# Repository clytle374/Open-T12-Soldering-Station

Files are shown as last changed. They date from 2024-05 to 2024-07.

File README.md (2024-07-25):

# Open-T12-Soldering-Station-
This is a clone of the cheap T12 soldering stations, attempting to eliminate the shortfalls of cheap.  Useless without the fine firmware from https://github.com/deividAlfa/stm32_soldering_iron_controller

It has provisions for a backup battery. Jumper selectable between internal and external NTC as some of the new handles don't contain a NTC, so this gives you the option if you don't want to add one to your handle.  There are also jumper option for configuring different soldering handles.  It is setup to use the 1.3” 6 pin OLED display.  

The pinouts match the KSGER stations for compatibility with the above mentioned handles. There is no provision for the real time clock in the firmware, I see it as useless.

Some of the cheap boards had issue with the linear voltage regulator dropping out from thermal protection as the power was quite high dropping from 24V to 3.3V.  This design uses a switching regulator to step down from 24V ot 5V, and then a 3.3V linear regulator for a clean 3.3V supply.

Much more information on the many models out there at the above mentioned site for the firmware. I created this as it is impossible to tell exactly what you are buying from the suppliers.

Front

PCB

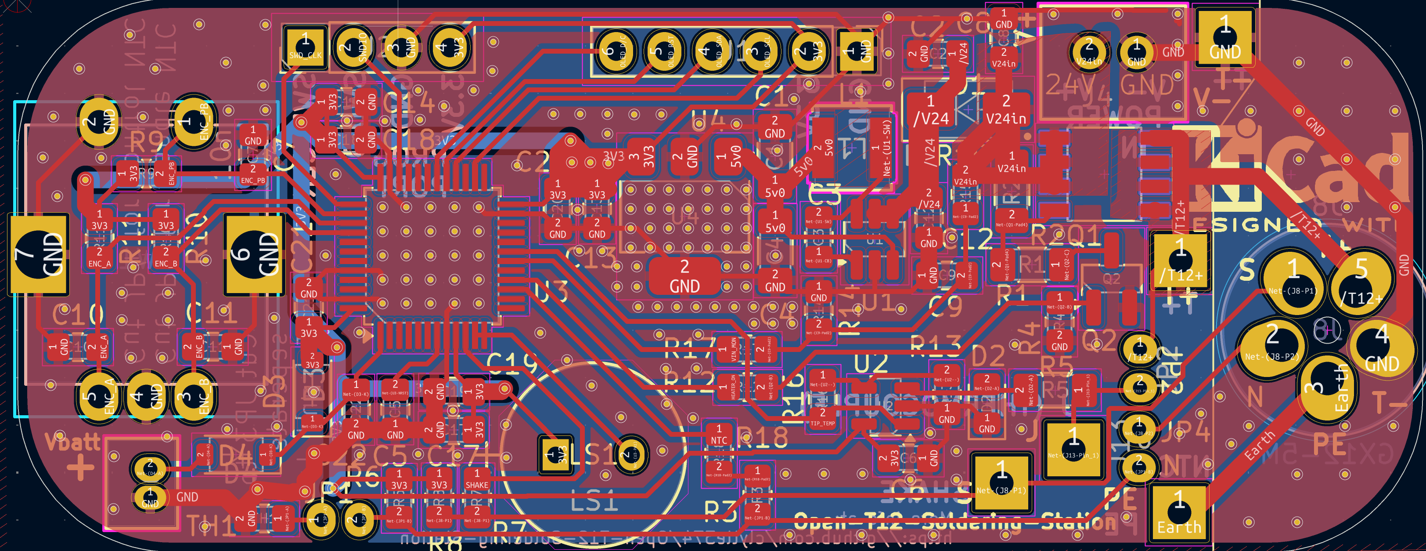
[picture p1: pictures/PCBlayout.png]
PCB Layout


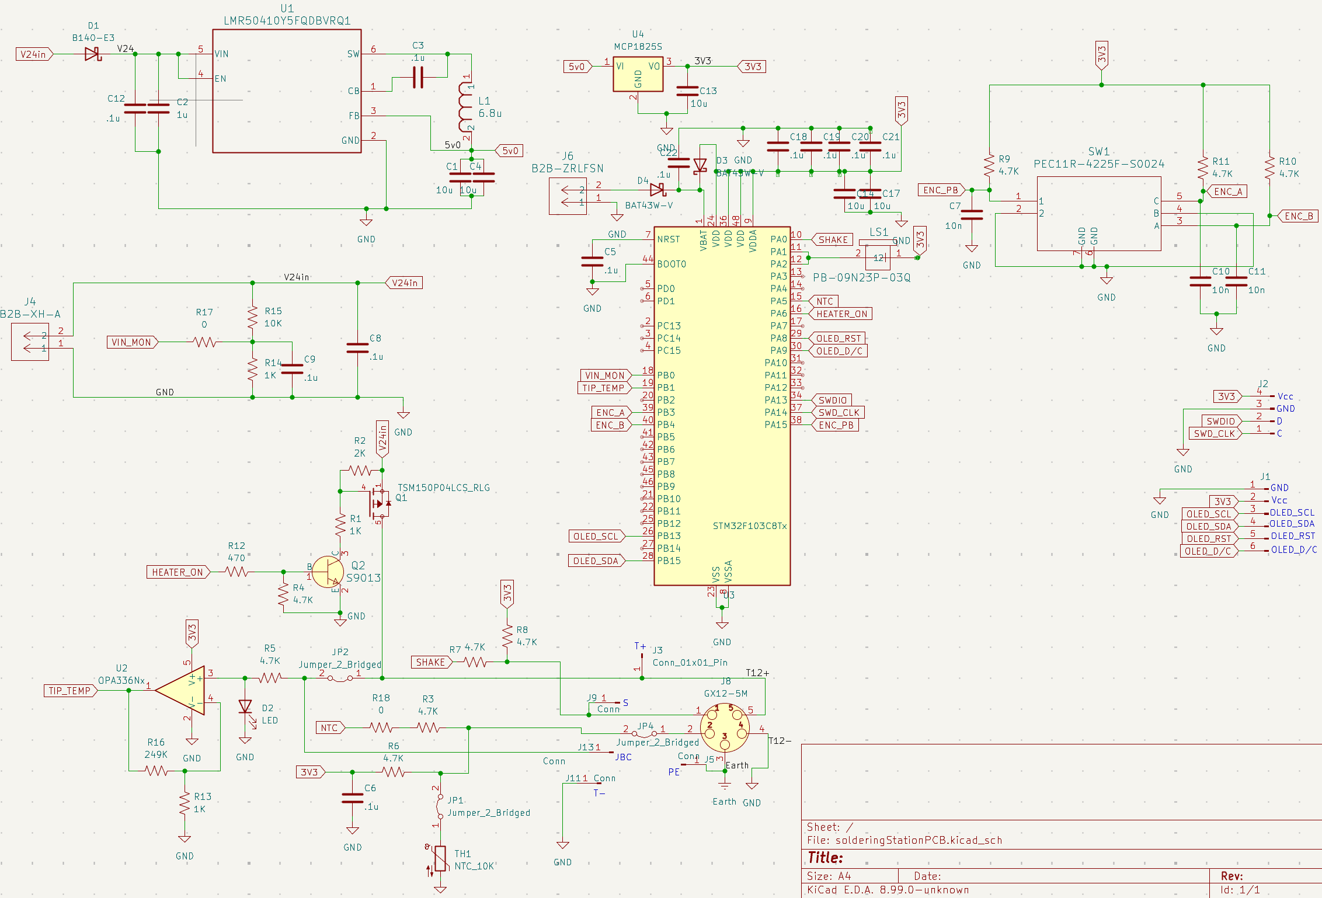
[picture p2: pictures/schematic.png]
Schematic


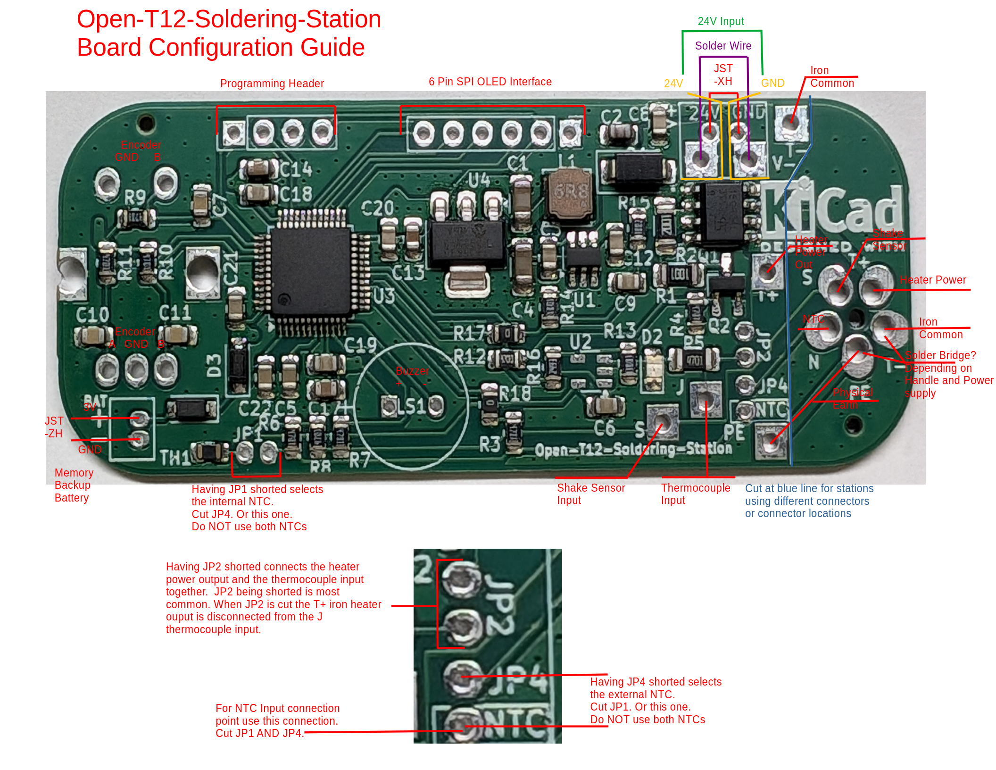
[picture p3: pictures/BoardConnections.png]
BoardConnections, Configuration


A limited run is available on Tindie.

https://www.tindie.com/products/clytle374/open-t12-soldering-station/

https://www.tindie.com/products/clytle374/open-t12-soldering-station-board-rohs-kit/

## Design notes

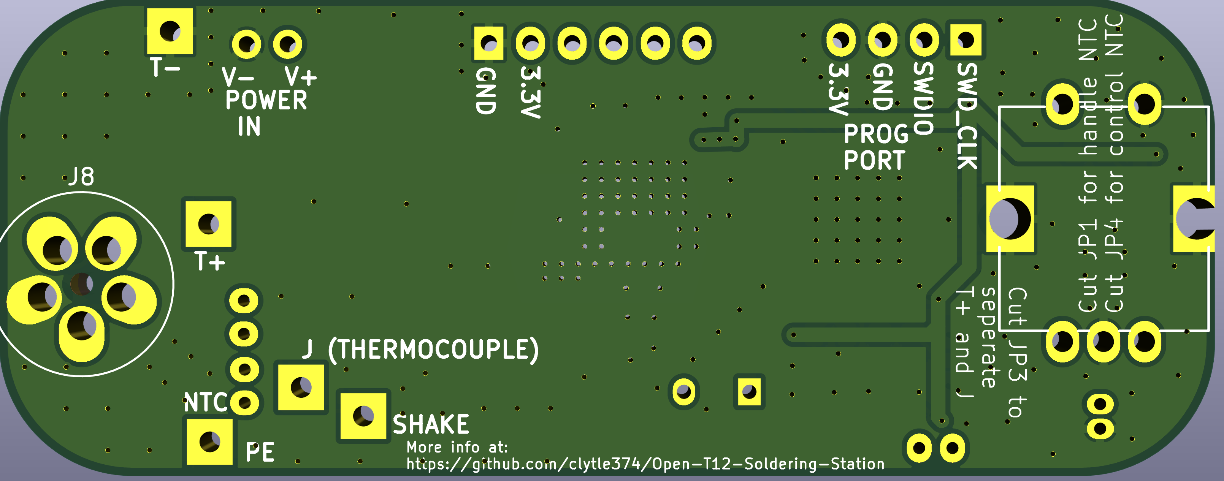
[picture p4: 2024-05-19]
pictures/backRender.png

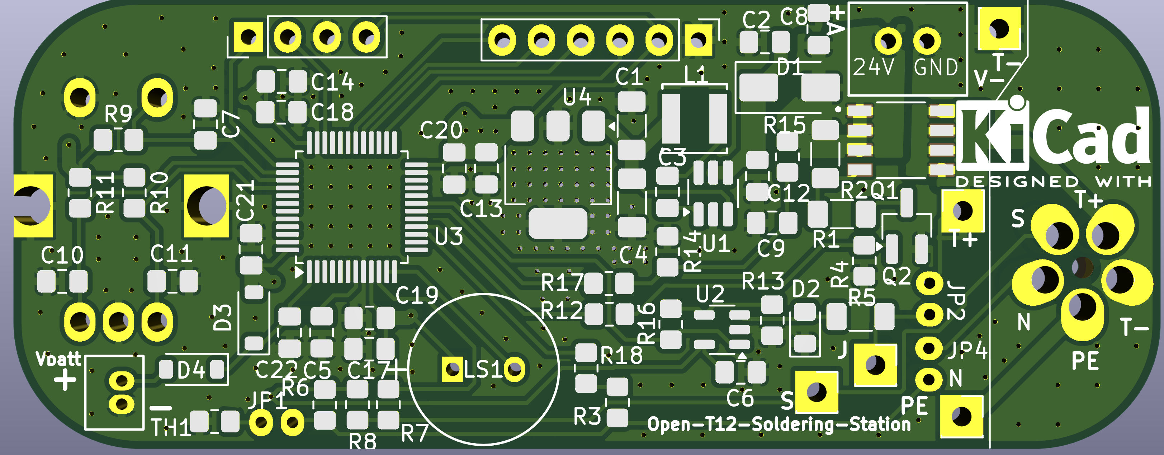
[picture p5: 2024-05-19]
pictures/frontRender.png

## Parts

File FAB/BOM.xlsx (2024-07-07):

Index | Manufacturer Part Number | Comment | Designator | JLCPCB Part # | Footprint
1 | TSM150P04LCS RLG | MOSFET P-CHANNEL 40V 22A 8SOP | Q1 | C557548 | SOP-8
2 | OPA336N/3K | IC OPAMP GP 1 CIRCUIT SOT23-5 | U2 | C882818
3 | CL21B103KBANNNC | CAP CER 10000PF 50V X7R 0805 | C10, C11, C7 | C1710 | 805
4 | BC817-40 | 45V 300mW 100@100mA,1.0V 500mA NPN SOT-23 Bipolar Transistors - BJT ROHS | Q2 | C20069155 | SOT-23
5 | B140-13-F | DIODE SCHOTTKY 40V 1A SMA | D1 | C15759 | SMA(DO-214AC)
6 | STM32F103C8T6 | IC MCU 32BIT 64KB FLASH 48LQFP | U3 | C8734 | LQFP-48(7x7)
7 | RC1206FR-071KL | RES 1K OHM 1% 1/4W 1206 | R1 | C131398 | 1206
8 | RC1206FR-072KL | RES 2K OHM 1% 1/4W 1206 | R2 | C133543 | 1206
9 | C0805C104M5RAC7800 | CAP CER 0.1UF 50V X7R 0805 | C3, C5, C6, C8, C9, C12, C18, C19, C20, C21, C22 | C3863412 | 805
12 | RT0805BRD074K7L | RES SMD 4.7K OHM 0.1% 1/8W 0805 | R3, R4 ,R6, R7, R8, R9, R10, R11 | C865532 | 805
13 | RT0805BRD07470RL | RES SMD 470 OHM 0.1% 1/8W 0805 | R12 | C17710 | 805
14 | RT0805BRD071KL | RES SMD 1K OHM 0.1% 1/8W 0805 | R13, R14 | C110774 | 805
15 | RT0805BRD0710KL | RES SMD 10K OHM 0.1% 1/8W 0805 | R15 | C110775 | 805
16 | RT0805BRD07249KL | RES SMD 249K OHM 0.1% 1/8W 0805 | R16 | C706231
17 | RC0805JR-070RL | RES 0 OHM JUMPER 1/8W 0805 | R17, R18 | C17477 | 805
18 | RT1206BRD074K7L | RES SMD 4.7K OHM 0.1% 1/4W 1206 | R5 | C17936 | 1206
19 | BAT43W-TP | DIODE SCHOTTKY 30V 200MA SOD123 | D3, D4 | C130885 | SOD-123
20 | SML-LX0805SRC-TR | LED RED CLEAR SMD | D2
28 | 74405042068 | FIXED IND 6.8UH 1.9A 156MOHM SMD | L1 | C2041796 | SMD,4x3.7mm
29 | LMR50410Y5FQDBVRQ1 | IC REG BUCK 5V 1A SOT23-6 | U1 | C2871822 | SOT-23-6
30 | C1206C106K8PAC7800 | CAP CER 10UF 10V X5R 1206 | C1 C4 | C141041 | 1206
31 | C2012X5R1H105K125AB | CAP CER 1UF 50V X5R 0805 | C2 | C3868498 | 805
32 | MCP1825ST-3302E/DB | IC REG LIN 3.3V 500MA SOT223-3 | U4 | C145411 | SOT-223
33 | NMC0805X5R106K6.3TRPLP2KF | CAP SMT080510F6.3VDC | C13, C14, C17 | C20101226 | 805
37 | ABNTC-0805-103J-3950F-T | THERMISTOR NTC 10KOHM 3950K 0805 | TH1 | C95968 | 805

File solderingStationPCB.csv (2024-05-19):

Reference | Value | Qty | Description | Footprint
C1 | 10u | 1 | C1206C106K8PAC7800 | Capacitor_SMD:C_1206_3216Metric_Pad1.33x1.80mm_HandSolder
C2 | 1u | 1 | C2012X5R1H105K125AB | Capacitor_SMD:C_0805_2012Metric_Pad1.18x1.45mm_HandSolder
C3 | .1u | 1 | C0805C104M5RAC7800 | Capacitor_SMD:C_0805_2012Metric_Pad1.18x1.45mm_HandSolder
C4 | 10u | 1 | C1206C106K8PAC7800 | Capacitor_SMD:C_1206_3216Metric_Pad1.33x1.80mm_HandSolder
C5 | .1u | 1 | C0805C104M5RAC7800 | Capacitor_SMD:C_0805_2012Metric_Pad1.18x1.45mm_HandSolder
C6 | .1u | 1 | C0805C104M5RAC7800 | Capacitor_SMD:C_0805_2012Metric_Pad1.18x1.45mm_HandSolder
C8 | .1u | 1 | C0805C104M5RAC7800 | Capacitor_SMD:C_0805_2012Metric_Pad1.18x1.45mm_HandSolder
C9 | .1u | 1 | C0805C104M5RAC7800 | Capacitor_SMD:C_0805_2012Metric_Pad1.18x1.45mm_HandSolder
C10 | 10n | 1 | CL21B103KBANNNC | Capacitor_SMD:C_0805_2012Metric_Pad1.18x1.45mm_HandSolder
C11 | 10n | 1 | CL21B103KBANNNC | Capacitor_SMD:C_0805_2012Metric_Pad1.18x1.45mm_HandSolder
C12 | .1u | 1 | C0805C104M5RAC7800 | Capacitor_SMD:C_0805_2012Metric_Pad1.18x1.45mm_HandSolder
C13 | 10u | 1 | TCCT6R3X106K1GV001E | Capacitor_SMD:C_0805_2012Metric_Pad1.18x1.45mm_HandSolder
C14 | 10u | 1 | TCCT6R3X106K1GV001E | Capacitor_SMD:C_0805_2012Metric_Pad1.18x1.45mm_HandSolder
C17 | 10u | 1 | TCCT6R3X106K1GV001E | Capacitor_SMD:C_0805_2012Metric_Pad1.18x1.45mm_HandSolder
C18 | .1u | 1 | C0805C104M5RAC7800 | Capacitor_SMD:C_0805_2012Metric_Pad1.18x1.45mm_HandSolder
C19 | .1u | 1 | C0805C104M5RAC7800 | Capacitor_SMD:C_0805_2012Metric_Pad1.18x1.45mm_HandSolder
C20 | .1u | 1 | C0805C104M5RAC7800 | Capacitor_SMD:C_0805_2012Metric_Pad1.18x1.45mm_HandSolder
C21 | .1u | 1 | C0805C104M5RAC7800 | Capacitor_SMD:C_0805_2012Metric_Pad1.18x1.45mm_HandSolder
C22 | .1u | 1 | C0805C104M5RAC7800 | Capacitor_SMD:C_0805_2012Metric_Pad1.18x1.45mm_HandSolder
D1 | B140-E3 | 1 | 40V 1A Schottky Barrier Rectifier Diode, SMA(DO-214AC) | Diode_SMD:D_SMA
D2 | LED | 1 | SML-LX0805SRC-TR | LED_SMD:LED_0805_2012Metric_Pad1.15x1.40mm_HandSolder
D3 | BAT43W-V | 1 | 30V 0.2A Small Signal Schottky diode, SOD-123 | Diode_SMD:D_SOD-123
D4 | BAT43W-V | 1 | 30V 0.2A Small Signal Schottky diode, SOD-123 | Diode_SMD:D_SOD-123
J1 | Conn_01x06_Pin | 1 | Generic connector, single row, 01x06, script generated | Connector_PinHeader_2.54mm:PinHeader_1x06_P2.54mm_Vertical
J2 | Conn_01x04_Pin | 1 | Generic connector, single row, 01x04, script generated | Connector_PinHeader_2.54mm:PinHeader_1x04_P2.54mm_Vertical
J3 | Conn_01x01_Pin | 1 | Generic connector, single row, 01x01, script generated | Connector_PinSocket_2.54mm:PinSocket_1x01_P2.54mm_Vertical
J4 | B2B-XH-A | 1 |  | footprints:CONN_B2B-XH-A_JST
J5 | Conn | 1 | Generic connector, single row, 01x01, script generated | Connector_PinSocket_2.54mm:PinSocket_1x01_P2.54mm_Vertical
J6 | B2B-ZRLFSN | 1 |  | footprints:CONN_B2B-ZRLFSN_JST
J8 | GX12-5M | 1 | XLR Connector, Male or Female, 5 Pins | footprints:GX12-5M
J9 | Conn | 1 | Generic connector, single row, 01x01, script generated | Connector_PinSocket_2.54mm:PinSocket_1x01_P2.54mm_Vertical
J11 | Conn | 1 | Generic connector, single row, 01x01, script generated | Connector_PinSocket_2.54mm:PinSocket_1x01_P2.54mm_Vertical
J13 | Conn | 1 | Generic connector, single row, 01x01, script generated | Connector_PinSocket_2.54mm:PinSocket_1x01_P2.54mm_Vertical
JP1 | Jumper_2_Bridged | 1 | Jumper, 2-pole, closed/bridged | footprints:JUMPER_SNIPABLE
JP2 | Jumper_2_Bridged | 1 | Jumper, 2-pole, closed/bridged | footprints:JUMPER_SNIPABLE
JP4 | Jumper_2_Bridged | 1 | Jumper, 2-pole, closed/bridged | footprints:JUMPER_SNIPABLE
L1 | 6.8u | 1 | 74405042068 | footprints:IND_042068_WRE
LS1 | PB-09N23P-03Q | 1 |  | footprints:PB-09N23P-03Q_MAL
Q1 | TSM150P04LCS_RLG | 1 |  | footprints:TRANS_TSM150P04LCS_RLG
Q2 | S9013 | 1 | TRANS NPN 25V 0.6A TO-18 | Package_TO_SOT_SMD:SOT-23_Handsoldering
R1 | 1K | 1 | RC1206FR-071KL | Resistor_SMD:R_1206_3216Metric_Pad1.30x1.75mm_HandSolder
R2 | 2K | 1 | RC1206FR-072KL | Resistor_SMD:R_1206_3216Metric_Pad1.30x1.75mm_HandSolder
R3 | 4.7K | 1 | RT0805BRD074K7L | Resistor_SMD:R_0805_2012Metric_Pad1.20x1.40mm_HandSolder
R4 | 4.7K | 1 | RT0805BRD074K7L | Resistor_SMD:R_0805_2012Metric_Pad1.20x1.40mm_HandSolder
R5 | 4.7K | 1 | RT1206BRD074K7L | Resistor_SMD:R_1206_3216Metric_Pad1.30x1.75mm_HandSolder
R6 | 4.7K | 1 | RT0805BRD074K7L | Resistor_SMD:R_0805_2012Metric_Pad1.20x1.40mm_HandSolder
R7 | 4.7K | 1 | RT0805BRD074K7L | Resistor_SMD:R_0805_2012Metric_Pad1.20x1.40mm_HandSolder
R8 | 4.7K | 1 | RT0805BRD074K7L | Resistor_SMD:R_0805_2012Metric_Pad1.20x1.40mm_HandSolder
R9 | 4.7K | 1 | RT0805BRD074K7L | Resistor_SMD:R_0805_2012Metric_Pad1.20x1.40mm_HandSolder
R10 | 4.7K | 1 | RT0805BRD074K7L | Resistor_SMD:R_0805_2012Metric_Pad1.20x1.40mm_HandSolder
R11 | 4.7K | 1 | RT0805BRD074K7L | Resistor_SMD:R_0805_2012Metric_Pad1.20x1.40mm_HandSolder
R12 | 470 | 1 | RT0805BRD07470RL | Resistor_SMD:R_0805_2012Metric_Pad1.20x1.40mm_HandSolder
R13 | 1K | 1 | RT0805BRD071KL | Resistor_SMD:R_0805_2012Metric_Pad1.20x1.40mm_HandSolder
R14 | 1K | 1 | RT0805BRD071KL | Resistor_SMD:R_0805_2012Metric_Pad1.20x1.40mm_HandSolder
R15 | 10K | 1 | RT0805BRD0710KL | Resistor_SMD:R_0805_2012Metric_Pad1.20x1.40mm_HandSolder
R16 | 249K | 1 | RT0805BRD07249KL | Resistor_SMD:R_0805_2012Metric_Pad1.20x1.40mm_HandSolder
R17 | 0 | 1 |  | Resistor_SMD:R_0805_2012Metric_Pad1.20x1.40mm_HandSolder
R18 | 0 | 1 |  | Resistor_SMD:R_0805_2012Metric_Pad1.20x1.40mm_HandSolder
SW1 | PEC11R-4225F-S0024 | 1 |  | footprints:SW5_PEC11R-4225F-S0024_BRN
TH1 | NTC_10K | 1 | ABNTC-0805-103J-3950F-T | Resistor_SMD:R_0805_2012Metric_Pad1.20x1.40mm_HandSolder
U1 | LMR50410Y5FQDBVRQ1 | 1 |  | Package_TO_SOT_SMD:SOT-23-6_Handsoldering
U2 | OPA336Nx | 1 | 100 KHz, microPower CMOS, Op Amps, SOT-23-5 | Package_TO_SOT_SMD:SOT-23-5
U3 | STM32F103C8Tx | 1 | STMicroelectronics Arm Cortex-M3 MCU, 64KB flash, 20KB RAM, 72 MHz, 2.0-3.6V, 37 GPIO, LQFP48 | Package_QFP:LQFP-48_7x7mm_P0.5mm
U4 | MCP1825S | 1 | 500mA, Low-Voltage, Low Quiescent Current LDO Regulator, SOT-223, TO-220, TO-263 | Package_TO_SOT_SMD:SOT-223-3_TabPin2

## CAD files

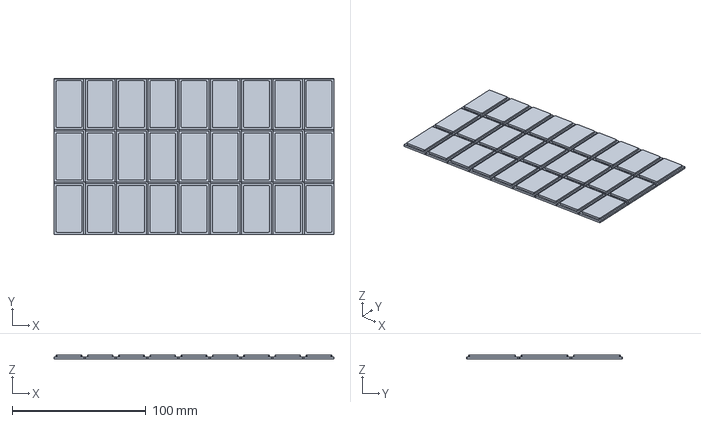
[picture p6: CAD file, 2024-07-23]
faceCad/windowCNC.FCStd
209.3 x 116.3 x 3.17 mm

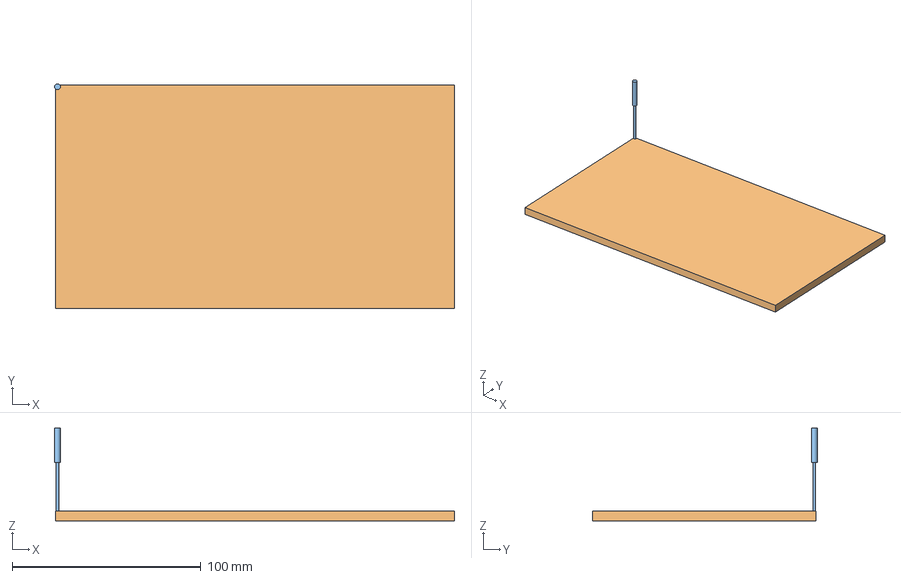
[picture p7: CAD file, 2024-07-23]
faceCad/windowCNCpanesFinish.FCStd
211.9 x 118.9 x 49.3 mm
Model-Body
Stock
Endmill003

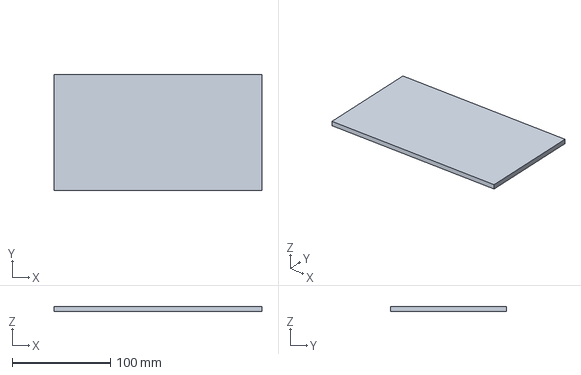
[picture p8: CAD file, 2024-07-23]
faceCad/windowCNCPartOff.FCStd
211.3 x 118.3 x 5.17 mm

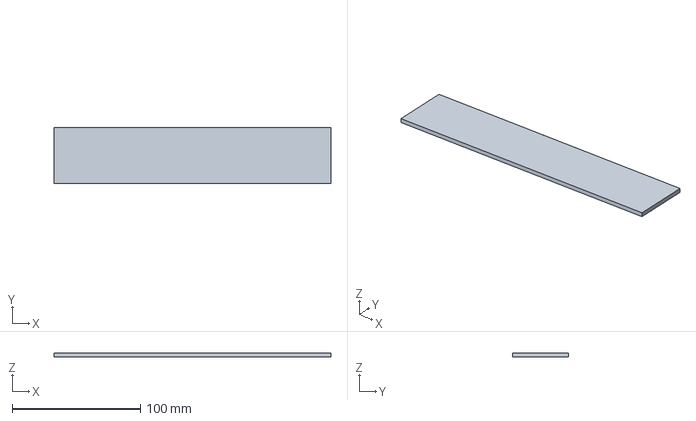
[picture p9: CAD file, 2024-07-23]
faceCad/windowTest.FCStd
216.4 x 43.7 x 3.17 mm

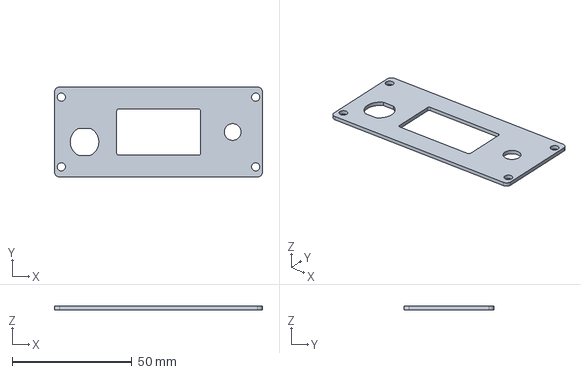
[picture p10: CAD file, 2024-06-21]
faceCad/facePlate.FCStd
87.0 x 37.6 x 1.50 mm

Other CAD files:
faceCad/window.FCStd
faceCad/windowCNCRough.FCStd

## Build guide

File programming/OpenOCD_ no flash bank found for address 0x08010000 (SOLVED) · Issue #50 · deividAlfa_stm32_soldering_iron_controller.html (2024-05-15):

Skip to content

## Navigation Menu

# Global navigation

© 2024 GitHub, Inc.

About (https://github.com/about) Blog (https://github.blog) Terms (https://docs.github.com/site-policy/github-terms/github-terms-of-service) Privacy (https://docs.github.com/site-policy/privacy-policies/github-privacy-statement) Security (https://github.com/security) Status (https://www.githubstatus.com/)

(https://github.com/)

deividAlfa / stm32_soldering_iron_controller

# Navigate back to

- deividAlfa
- stm32_soldering_iron_controller

Type / to search

Command palette

# Search code, repositories, users, issues, pull requests...

Search

Clear

Search syntax tips (https://docs.github.com/search-github/github-code-search/understanding-github-code-search-syntax)

Give feedback

# Provide feedback

We read every piece of feedback, and take your input very seriously.

Include my email address so I can be contacted

Cancel Submit feedback

# Saved searches

## Use saved searches to filter your results more quickly

Name

Query

To see all available qualifiers, see our documentation (https://docs.github.com/search-github/github-code-search/understanding-github-code-search-syntax).

Cancel Create saved search

Create new... Issues Pull requests

Notifications



# Account menu



clytle374 Cory Lytle

Create new...

- New repository
- Import repository
- New codespace
- New gist (https://gist.github.com/)
- New organization

Dismiss alert

/ ... /

deividAlfa / stm32_soldering_i... / Issues #50 /

Clear Command Palette

Tip: Type # to search pull requests

Type ? for help and tips

Tip: Type # to search issues

Type ? for help and tips

Tip: Type # to search discussions

Type ? for help and tips

Tip: Type ! to search projects

Type ? for help and tips

Tip: Type @ to search teams

Type ? for help and tips

Tip: Type @ to search people and organizations

Type ? for help and tips

Tip: Type > to activate command mode

Type ? for help and tips

Tip: Go to your accessibility settings to change your keyboard shortcuts

Type ? for help and tips

Tip: Type author:@me to search your content

Type ? for help and tips

Tip: Type is:pr to filter to pull requests

Type ? for help and tips

Tip: Type is:issue to filter to issues

Type ? for help and tips

Tip: Type is:project to filter to projects

Type ? for help and tips

Tip: Type is:open to filter to open content

Type ? for help and tips

We’ve encountered an error and some results aren't available at this time. Type a new search or try again later.

No results matched your search

Search for issues and pull requests # Search for issues, pull requests, discussions, and projects # Search for organizations, repositories, and users @ Search for projects ! Search for files / Activate command mode > Search your issues, pull requests, and discussions # author:@me Search your issues, pull requests, and discussions # author:@me Filter to pull requests # is:pr Filter to issues # is:issue Filter to discussions # is:discussion Filter to projects # is:project Filter to open issues, pull requests, and discussions # is:open

New issue

Jump to bottom

# OpenOCD: no flash bank found for address 0x08010000 (SOLVED) #50

Closed

chtaube opened this issue Mar 18, 2023 · 3 comments

Closed

# OpenOCD: no flash bank found for address 0x08010000 (SOLVED) #50

chtaube opened this issue Mar 18, 2023 · 3 comments

## Comments

@chtaube

Sorry, something went wrong.

Quote reply

### chtaube commented Mar 18, 2023

I just ran into an issue where flashing the chip with OpenOCD fails with this message:

❯ openocd
Open On-Chip Debugger 0.11.0
Licensed under GNU GPL v2
For bug reports, read
http://openocd.org/doc/doxygen/bugs.html
Info : auto-selecting first available session transport "hla_swd". To override use 'transport select <transport>'.
Info : The selected transport took over low-level target control. The results might differ compared to plain JTAG/SWD
Info : clock speed 1000 kHz
Info : STLINK V3J8M3B5S1 (API v3) VID:PID 0483:3753
Info : Target voltage: 3.280266
Info : stm32f1x.cpu: hardware has 6 breakpoints, 4 watchpoints
Info : starting gdb server for stm32f1x.cpu on 3333
Info : Listening on port 3333 for gdb connections
target halted due to debug-request, current mode: Thread
xPSR: 0x01000000 pc: 0x08003340 msp: 0x20005000
Info : device id = 0x20036410
Info : flash size = 64kbytes
target halted due to debug-request, current mode: Thread
xPSR: 0x01000000 pc: 0x08003340 msp: 0x20005000
target halted due to debug-request, current mode: Thread
xPSR: 0x01000000 pc: 0x08003340 msp: 0x20005000
** Programming Started **
Warn : no flash bank found for address 0x08010000
** Programming Finished **
** Verify Started **
Error: checksum mismatch - attempting binary compare
embedded:startup.tcl:530: Error: ** Verify Failed **
in procedure 'script'
at file "embedded:startup.tcl", line 26
in procedure 'program' called at file "openocd.cfg", line 13
in procedure 'program_error' called at file "embedded:startup.tcl", line 591
at file "embedded:startup.tcl", line 530

Same error message when trying to flash the stock firmware, so device was sort of bricked. But...

After some investigation I found OpenOCD's scripts for the stm32f1x platform were designed to support the "official" 64k flash size only and trying to flash larger program sizes results in the above message.

The OpenOCD documentation gives a hint how to resolve this: https://openocd.org/doc/html/Flash-Commands.html#index-stm32f1x

This forum post (in German language) has a practical solution that worked for me: https://www.mikrocontroller.net/articles/STM32F103C8T6_STM32_Billig_Board

What I did:

in /usr/share/openocd/scripts/target/ – copy stm32f1x.cfg to stm32f103.cfg

open stm32f103.cfg in an editor, search for this line:
flash bank $_FLASHNAME stm32f1x 0x08000000 $_FLASH_SIZE 0 0 $_TARGETNAME

replace with:
flash bank $_FLASHNAME stm32f1x 0 0x20000 0 0 $_TARGETNAME

in your projects openocd.cfg file, change the target to your newly saved target definition:
source [find target/stm32f103.cfg]

re-run openocd, flashing should succeed now:

❯ openocd
Open On-Chip Debugger 0.11.0
Licensed under GNU GPL v2
For bug reports, read
http://openocd.org/doc/doxygen/bugs.html
Info : J-Link V10 compiled Mar 21 2019 15:43:57
Info : Hardware version: 10.10
Info : VTarget = 3.296 V
Info : clock speed 1000 kHz
Info : SWD DPIDR 0x1ba01477
Info : stm32f1x.cpu: hardware has 6 breakpoints, 4 watchpoints
Info : starting gdb server for stm32f1x.cpu on 3333
Info : Listening on port 3333 for gdb connections
target halted due to debug-request, current mode: Thread
xPSR: 0x01000000 pc: 0x080032ac msp: 0x20002800
Info : device id = 0x20036410
Info : ignoring flash probed value, using configured bank size
Info : flash size = 128kbytes
target halted due to debug-request, current mode: Thread
xPSR: 0x01000000 pc: 0x080032ac msp: 0x20002800
target halted due to debug-request, current mode: Thread
xPSR: 0x01000000 pc: 0x080032ac msp: 0x20002800
** Programming Started **
** Programming Finished **
** Verify Started **
** Verified OK **
Info : Listening on port 6666 for tcl connections
Info : Listening on port 4444 for telnet connections

The text was updated successfully, but these errors were encountered:

- 👍
- 👎
- 😄
- 🎉
- 😕
- ❤️
- 🚀
- 👀

All reactions

@chtaube chtaube closed this as completed Mar 18, 2023

@deividAlfa

Sorry, something went wrong.

Quote reply

Owner

### deividAlfa commented Mar 18, 2023

Thanks. Actually I never used OpenOCD, was submitted by a user.

- 👍
- 👎
- 😄
- 🎉
- 😕
- ❤️
- 🚀
- 👀

All reactions

Sorry, something went wrong.

@clytle374

Sorry, something went wrong.

Quote reply

### clytle374 commented Feb 8, 2024

### Choose a reason for hiding this comment

The reason will be displayed to describe this comment to others. Learn more about hiding comments (https://docs.github.com/articles/managing-disruptive-comments/#hiding-a-comment).

Hide comment

I got bit by this one tonight. Changes from chtaube worked.

It did terminate in this, should I be concerned?
xPSR: 0x01000000 pc: 0x08004150 msp: 0x20002800 ** Programming Started ** Warn : Adding extra erase range, 0x08018e70 .. 0x08018fff ** Programming Finished **

- 👍
- 👎
- 😄
- 🎉
- 😕
- ❤️
- 🚀
- 👀

👍 1 chtaube reacted with thumbs up emoji

All reactions

- 👍 1 reaction

Sorry, something went wrong.

@deividAlfa

Sorry, something went wrong.

Quote reply

Owner

### deividAlfa commented Feb 8, 2024

If It works, it works, simple as that 👍🏻

- 👍
- 👎
- 😄
- 🎉
- 😕
- ❤️
- 🚀
- 👀

All reactions

Sorry, something went wrong.

@clytle374

#### Add a comment

Comment

Write Preview

Heading

Bold

Italic

Quote

Code

Link

Numbered list

Unordered list

Task list

Attach files

Mention

Reference

Saved replies

Slash commands

Menu

- Heading
- Bold
- Italic
- Quote
- Code
- Link
- Numbered list
- Unordered list
- Task list
- Attach files
- Mention
- Reference
- Saved replies
- Slash commands

# Select a reply

Create a new saved reply

There was an error creating your Issue.

Slash commands

Beta

Give feedback

Slash commands

Beta

Give feedback

#### An unexpected error has occurred

Add your comment here...

We don’t support that file type.

Try again with GIF, JPEG, JPG, MOV, MP4, PNG, SVG, WEBM, CPUPROFILE, CSV, DMP, DOCX, FODG, FODP, FODS, FODT, GZ, JSON, JSONC, LOG, MD, ODF, ODG, ODP, ODS, ODT, PATCH, PDF, PPTX, TGZ, TXT, XLS, XLSX or ZIP.

Attaching documents requires write permission to this repository.

Try again with GIF, JPEG, JPG, MOV, MP4, PNG, SVG, WEBM, CPUPROFILE, CSV, DMP, DOCX, FODG, FODP, FODS, FODT, GZ, JSON, JSONC, LOG, MD, ODF, ODG, ODP, ODS, ODT, PATCH, PDF, PPTX, TGZ, TXT, XLS, XLSX or ZIP.

This file is empty.

Try again with a file that’s not empty.

This file is hidden.

Try again with another file.

Something went really wrong, and we can’t process that file.

Try again.

Markdown is supported (https://docs.github.com/github/writing-on-github/getting-started-with-writing-and-formatting-on-github/basic-writing-and-formatting-syntax)

Paste, drop, or click to add files

Nothing to preview

Comment

Remember, contributions to this repository should follow our GitHub Community Guidelines (https://docs.github.com/articles/github-community-guidelines).

Assignees

No one assigned

Labels

None yet

Projects

None yet

Milestone

No milestone

Development

No branches or pull requests

Sorry, something went wrong and we weren't able to fetch your subscription status. Retry

3 participants

@chtaube @clytle374 @deividAlfa

## Footer

(https://github.com) © 2024 GitHub, Inc.

You can’t perform that action at this time.

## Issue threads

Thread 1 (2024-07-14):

Kicad project was created using a development version

clytle374, 2024-07-14:
This means for now it can only be opened with a nightly, or development version.

Didn't think of this issue and I run Kicad from git source.

clytle374, 2024-07-16:
Here is a fork that had a forced downgrade so it can be opened with a current version.  Please be careful as it was reported to have thrown some errors in the process
https://github.com/hevanaa/Open-T12-Soldering-Station

Closed 2024-07-16.

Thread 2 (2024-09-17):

compatibility w JBC 245?

PolyEng, 2024-09-17:
Hi , i just wanted to know if this board is compatible with 245 tip series from jbc ? , i modded a ksger with the same fw you use on your custom board but cant get the 245 tips to work, so i'm searching for a better hw to use, and your board seem very well made.

clytle374, 2024-09-18:
I honestly can't keep track of all the variants that exist.  It should be compatible with any tips the T12 controllers are normally compatible with.
Sorry I can't answer this

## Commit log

2024-05-15 test commit
    [PCBcad.FCStd, ocd-program.cfg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]
2024-05-15 reworked layout after prototype testing
    [solderingStationPCB.kicad_sch]
2024-05-15 schematic PDF
2024-05-16 remove trash
    [PCBcad.FCStd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]
2024-05-16 cleanup and fixes
    [solderingStationPCB.kicad_pcb, solderingStationPCB.kicad_sch]
2024-05-16 improve slikscreen
    [solderingStationPCB.kicad_pcb]
2024-05-18 fixed lables and cleanup
    [solderingStationPCB.kicad_pcb, solderingStationPCB.kicad_sch]
2024-05-19 added info to board, enlarged pads and holes, new pics
    [solderingStationPCB.kicad_pcb]
2024-05-19 fix pic
    [solderingStationPCB.kicad_pcb]
2024-06-01 clairify schematic
    [solderingStationPCB.kicad_pcb, solderingStationPCB.kicad_sch]
2024-06-21 replaced Q2 with better rated part
    [faceEdgeCuts.kicad_pcb, facePlate.FCStd, solderingStationPCB.kicad_pcb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]
2024-07-23 status update
    [window.FCStd, windowCNC.FCStd, windowCNCPartOff.FCStd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]
2024-07-25 remove trash folders
    [dewalt.FCStd]
2024-08-26 increase T+ trace
    [solderingStationPCB.kicad_pcb]
